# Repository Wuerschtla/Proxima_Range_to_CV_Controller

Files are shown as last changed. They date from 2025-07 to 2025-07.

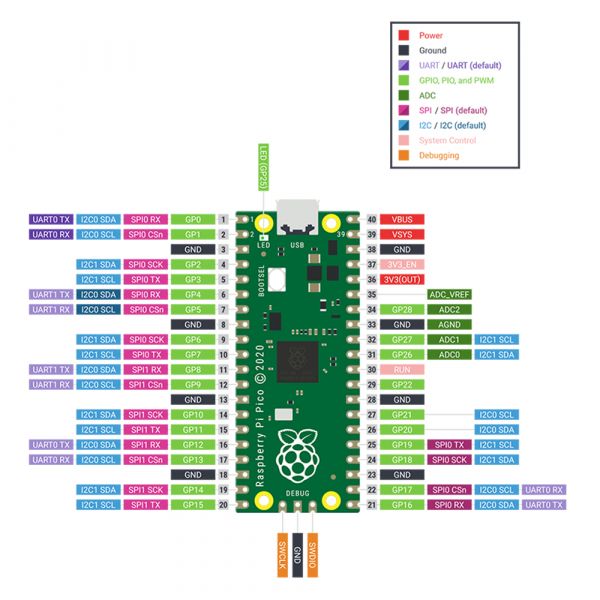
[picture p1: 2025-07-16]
Pinouts/Raspi_Pico_Pinout.jpg

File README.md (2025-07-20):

# Proxima

A Eurorack module that measures the distance using a VL53L0X Time-of-Flight sensor and converts it into a Control Voltage (CV) for your modular system.
Control parameters easily with hand movements in the air.

⸻

# Installation
1.	Install CircuitPython on the Pico
2.	Download this repository
3.	"Proxima_R2CV.py" to the Pico
4.  Rename "Proxima_R2CV.py" to "code.py" to start the program automatically after connecting the power supply.
5.	Copy the contents of the circuit_pytho_libs folder into the lib folder on the Pico

____

## Features
•	Distance range: 2 cm to 20 cm

•	CV output: 0 V to 8 V

•	Smooth values using a moving average filter

⸻

## Schematics for:
•	Complete wiring

•	LM358 amplifier circuit

•	Low-pass filter

are located in the schematics/ folder.

⸻

### Estimated Cost
The module can be built from inexpensive components. Approximate prices:

•	Raspberry Pi Pico: 5–6 €

•	LM358 Op-Amp: 0.50 €

•	MCP4725 (12-bit DAC): 3–4 €

•	VL53L0X ToF sensor: 4–5 €

•	Resistors and capacitors: 1-2 €

•	Jumper wires and connectors: 1–2 €

Total: about 15–20 € (depending on supplier and shipping).

# text-based complete scheme

### 1. Pico:
VSYS (Pin 39) to +5v Eurorack

GND (Pin 38) to GND Eurorack

SDA (Pin 6) to SDA from Tof Sensor and DAC

SCL (Pin 7) to SCL from Tof Sensor and DAC

+3.3v (Pin 36) to VCC from Tof Sensor and DAC

### 2. DAC (MCP4725) and Tof Sensor (VL53L0X)
GND from Tof Sensor and DAC to GND (Pin 3)

### 3. low-pass filter
Output from DAC through 10kOhm Resistor to branching point A

branching point A through 100nF Capasitor to GND

branching point A to LM358 (Pin 3)

### 4. Op-Amp (LM358)
LM358 (Pin 4) to GND

LM358 (Pin 8) to +12v Eurorack

LM358 (Pin 2) to branching point B

branching point B through 10kOhm Resistor to GND

branching point B though 10kOhm Resistor and 4.7kOhm Resistor to branching point C

LM358 (Pin 1) to branching point C

branching point C to Output in CV

## !Make sure that all grounds are connected to each other.!

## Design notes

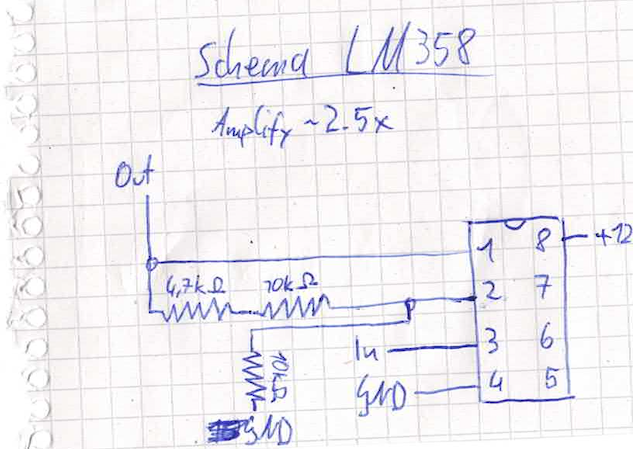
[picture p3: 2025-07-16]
schematics/scheme_LM358.png

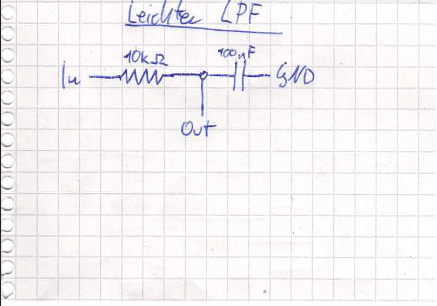
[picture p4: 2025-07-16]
schematics/scheme_LPF.png

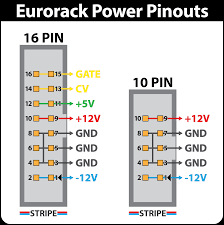
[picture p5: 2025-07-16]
Pinouts/EurorackPWSPinout.png

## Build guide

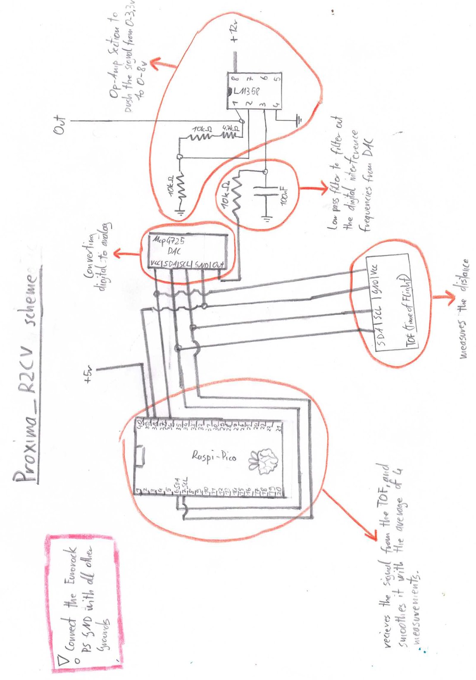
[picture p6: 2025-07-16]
schematics/complete_wiring_scheme.jpg

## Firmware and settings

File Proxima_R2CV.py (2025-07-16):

# mcp4725: DAC (Range: 0 - 4095, corresponds to 0 - 3.3V)
# vl53l0x: TOF Sensor

import board
import busio
import time
import adafruit_mcp4725
import adafruit_vl53l0x

MIN_CV = 0
MAX_CV = 8

# Maximale Länge der FIFO-Queue
# Nur ungerade Zahlen nehmen, damit die Berechnung funktioniert!
QUEUE_SIZE = 4

fifo_queue = [0] * QUEUE_SIZE

def add_to_fifo(val):
    fifo_queue.append(val)
    if len(fifo_queue) > QUEUE_SIZE:
        fifo_queue.pop(0)


i2c = busio.I2C(board.GP5, board.GP4)

dac = adafruit_mcp4725.MCP4725(i2c, address=0x60)
tof = adafruit_vl53l0x.VL53L0X(i2c, address=0x29)

def mean(values):
    clean = [v for v in values if isinstance(v, (int, float))]
    return sum(clean) / len(clean) if clean else MIN_CV

def median(values):
    sorted_vals = sorted(values)
    n = len(sorted_vals)
    if n == 0:
        return 0
    elif n % 2 == 1:
        return sorted_vals[n // 2]
    else:
        mid1 = sorted_vals[n // 2 - 1]
        mid2 = sorted_vals[n // 2]
        return (mid1 + mid2) / 2

def measure_distance():
    dist = tof.range
    return dist if dist > 0 else None

def distance_to_cv(distance_mm):
    if distance_mm is None or distance_mm > 200:  # über 20cm
        return MIN_CV  # minimaler CV-Wert
    elif distance_mm < 20:  # unter 2cm nicht definiert, hier min 2cm setzen
        distance_mm = 20
    # linear von 20cm=0.01V bis 2cm=8V
    # 20cm=200mm, 2cm=20mm
    voltage = MIN_CV + (MAX_CV - MIN_CV) * (200 - distance_mm) / (200 - 20)
    return max(MIN_CV, min(MAX_CV, voltage))


def distance_to_normalized_dac(distance_mm):
    if distance_mm is None or distance_mm > 200:  # über 20cm
        # Vermeide 0, da MCP4725-Library bei exakt 0 eine AssertionError wirft
        return MIN_CV
    elif distance_mm < 20:  # unter 2cm nicht definiert, hier min 2cm setzen
        distance_mm = 20
    # linear von 20cm=0.01V bis 2cm=8V
    # 20cm=200mm, 2cm=20mm
    dac.norm = (200 - distance_mm) / (200 - 20)
    return max(MIN_CV, min(1, dac.norm))

try:
    current_dac_value = 0

    while True:
        distance = measure_distance()
        add_to_fifo(distance)

        #dac_norm = distance_to_normalized_dac(distance)
        dist_mean = mean(fifo_queue)
        #dist_median = median(fifo_queue)
        dac_norm_mean = distance_to_normalized_dac(dist_mean)
        #dac_norm_median = distance_to_normalized_dac(dist_median)

        #print(f"Entfernung: {distance if distance is not None else 'N/A'} mm; FIFO: {fifo_queue}; mean_dist: {dist_mean:.2f}; median_dist: {dist_median:.2f}; DAC.norm.mean Wert: {dac_norm_mean:.2f}; DAC.norm.median Wert: {dac_norm_median:.2f}")

        # Setze den DAC Wert (normalisiert von 0 bis 1 = 3.3V)
        #dac.normalized_value = dac_norm
        dac.normalized_value = dac_norm_mean
        #dac.normalized_value = dac_norm_median
        
        # ca. TODO Hz Update für glatte Übergänge
        time.sleep(0.0001)  

except KeyboardInterrupt:
    print("\nProgramm beendet")
    dac.value = 0
